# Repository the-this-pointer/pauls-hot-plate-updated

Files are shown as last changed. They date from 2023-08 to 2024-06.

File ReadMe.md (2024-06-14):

#### Paul's Hotplate Upgraded

This is another version of awesome pauls hot plate project that I am working on. I designed a pcb for the project because I don't have access to the board he used in his project.
The project is not completed yet and I should do some modifications on the enclosure, and I need to change the firmware to support the new PCB. Also the enclosure and the PCB is not tested.

External component libraries located [here](https://github.com/the-this-pointer/kicad-my-libraries)

###### TODO:

- Firmware for new PCB
- Enclosure for new PCB

#### Images

The enclosure files and images are for revision `54e05cd389d`, the boards are changed afterwards and I will redesign enclosure.

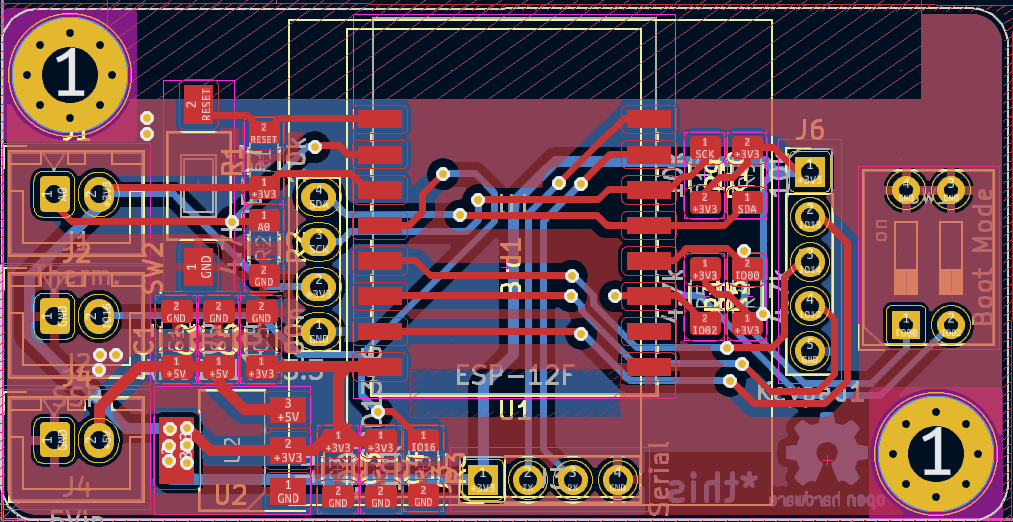
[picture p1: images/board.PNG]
PCB

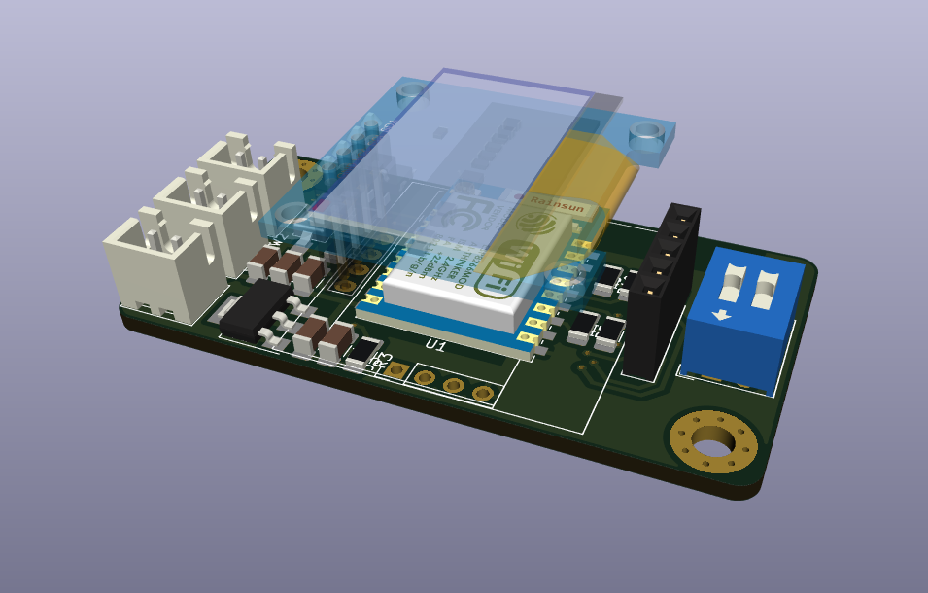
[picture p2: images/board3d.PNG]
3D Model

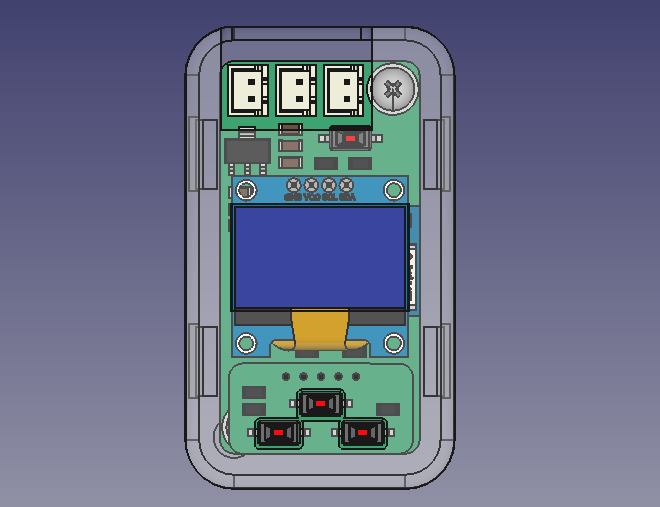
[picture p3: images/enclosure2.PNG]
Enclosure


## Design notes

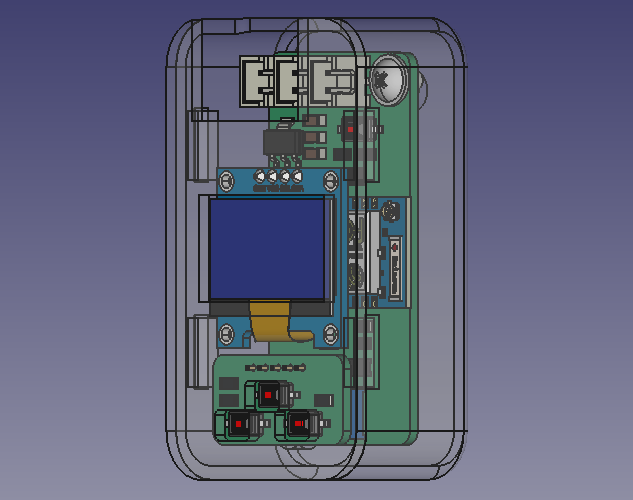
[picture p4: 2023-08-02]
images/enclosure3.PNG

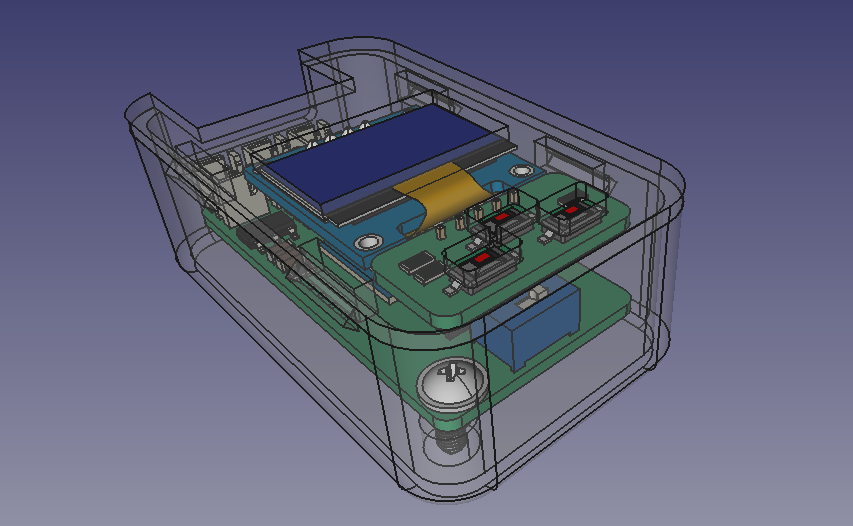
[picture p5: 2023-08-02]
images/enclosure1.PNG

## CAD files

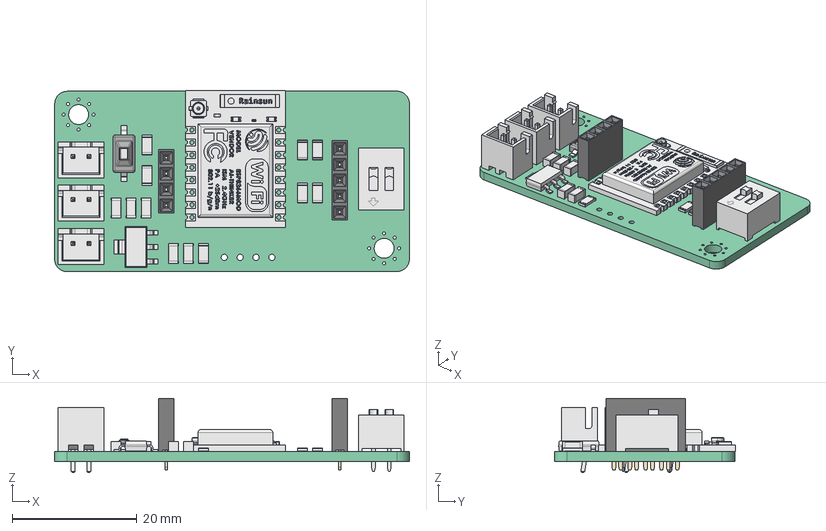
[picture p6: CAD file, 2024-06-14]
enclosure/MainBoard.FCStd
56.9 x 29.0 x 11.9 mm
Pcb_ba79
${REFERENCE}_R_1206_3216Metric_null
${REFERENCE}_JST_B2B_XH_A_null
pines
cuerpo
boton
Pin_One007
Epoxy_Body007
${REFERENCE}_C_1206_3216Metric_null
${REFERENCE}_R_1206_3216Metric_null001
${REFERENCE}_C_1206_3216Metric_null001
Pin_One006
Epoxy_Body006
${REFERENCE}_C_1206_3216Metric_null002
${REFERENCE}_R_1206_3216Metric_null002
ESP07
ESP008
ESP009
ESP010
ESP011
ESP012
ESP013
ESP014
ESP015
ESP016
ESP017
ESP018
ESP019
ESP020
ESP021
ESP022
ESP023
ESP024
ESP025
ESP026
ESP027
ESP028
ESP029
ESP030
ESP031
ESP032
ESP033
ESP034
ESP035
ESP036
ESP037
ESP038
ESP039
ESP040
ESP041
ESP042
ESP043
ESP044
ESP045
ESP046
ESP047
ESP048
ESP049
ESP050
ESP051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

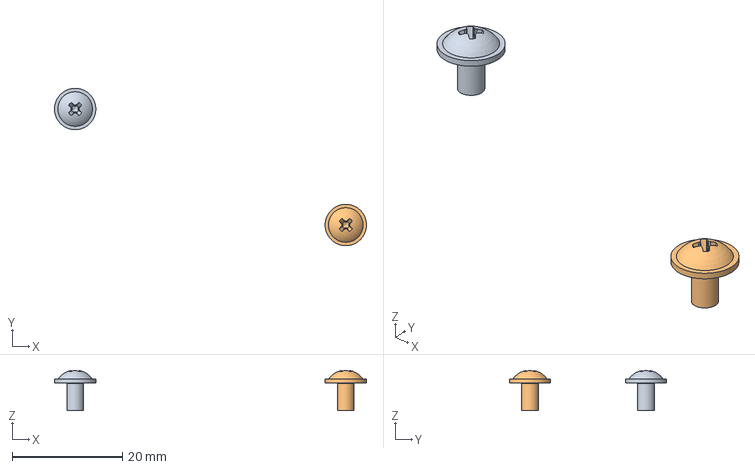
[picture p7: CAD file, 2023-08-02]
enclosure/BoardAssembled.FCStd
56.5 x 28.5 x 7.29 mm
M3x5-Screw
M3x5-Screw001

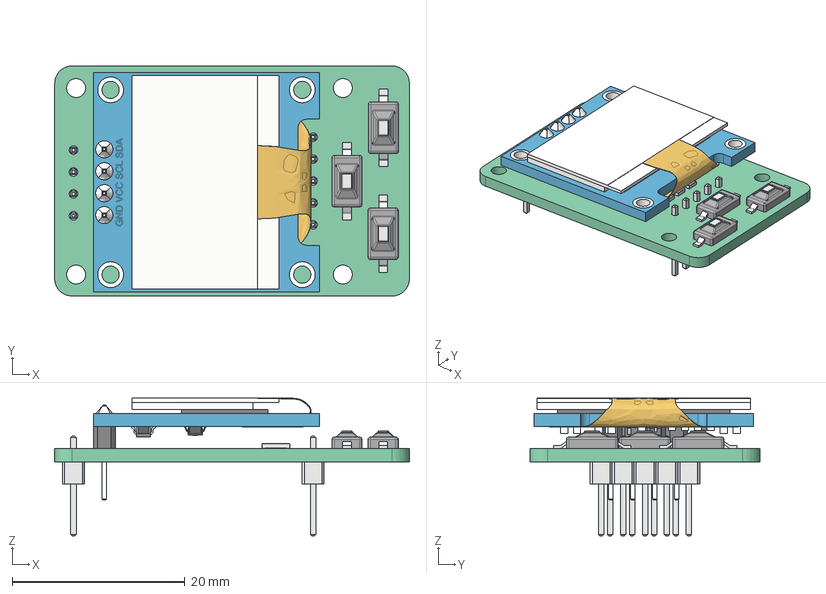
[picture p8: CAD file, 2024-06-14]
enclosure/Keypad.FCStd
41.1 x 26.7 x 15.9 mm
Pcb_ee0a
pines
cuerpo
boton
board
board001
board002
board003
board004
board005
board006
board007
board008
screen
screen001
screen002
pin_header
pin_header001
pin_header002
pin_header003
pin_header004
pin_header005
pin_header006
pin_header007
soldering
soldering001
soldering002
soldering003
smd_capacitor
smd_capacitor001
smd_capacitor002
smd_capacitor (1)
smd_capacitor (1)001
smd_capacitor (1)002
914_smd_resistor
914_smd_resistor001
914_smd_resistor002
472_smd_resistor
472_smd_resistor001
472_smd_resistor002
472_smd_resistor004
472_smd_resistor005
472_smd_resistor006
472_smd_resistor008
472_smd_resistor009
472_smd_resistor010
t4_smd_diode
t4_smd_diode001
t4_smd_diode002
smd_capacitor (2)
smd_capacitor (2)001
smd_capacitor (2)002
smd_capacitor (3)
smd_capacitor (3)001
smd_capacitor (3)002
smd_capacitor (4)
smd_capacitor (4)001
smd_capacitor (4)002
smd_capacitor (5)
smd_capacitor (5)001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

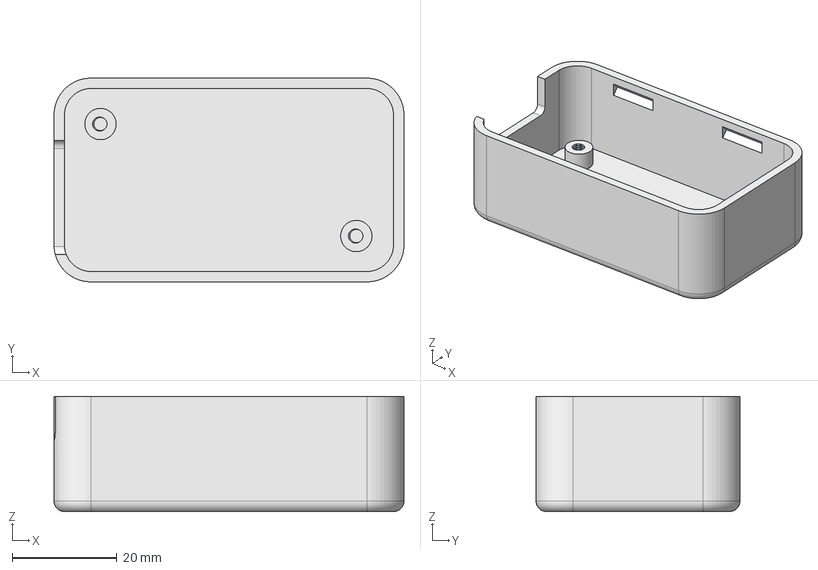
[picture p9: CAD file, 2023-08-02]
enclosure/BoxBody.FCStd
67.0 x 39.0 x 22.0 mm

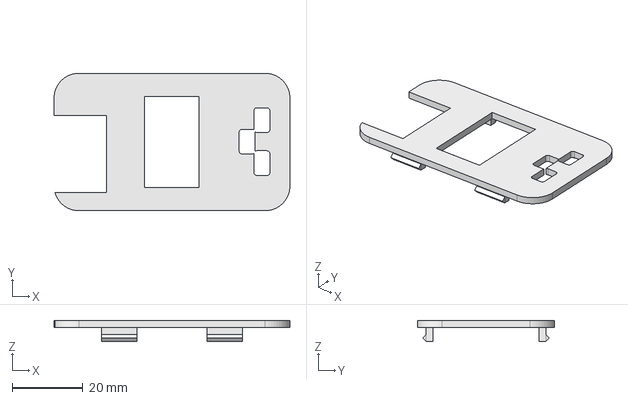
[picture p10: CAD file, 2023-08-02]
enclosure/BoxLead.FCStd
67.0 x 39.0 x 6.00 mm

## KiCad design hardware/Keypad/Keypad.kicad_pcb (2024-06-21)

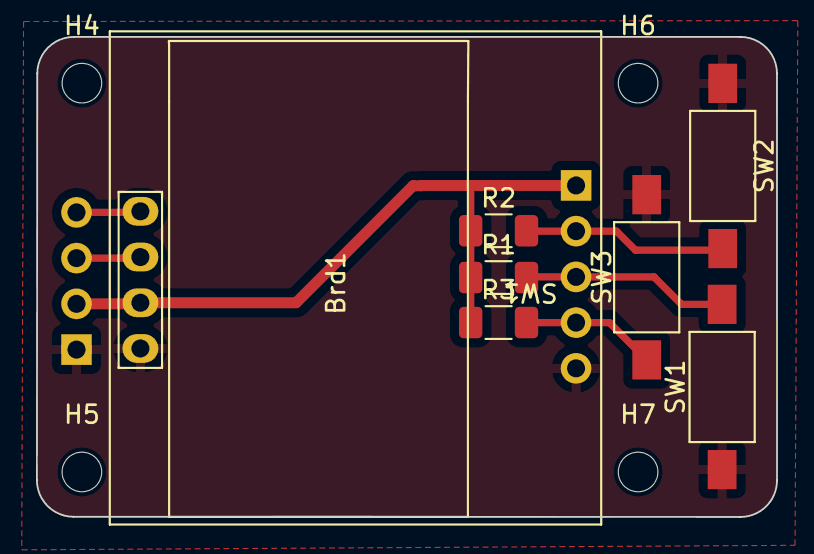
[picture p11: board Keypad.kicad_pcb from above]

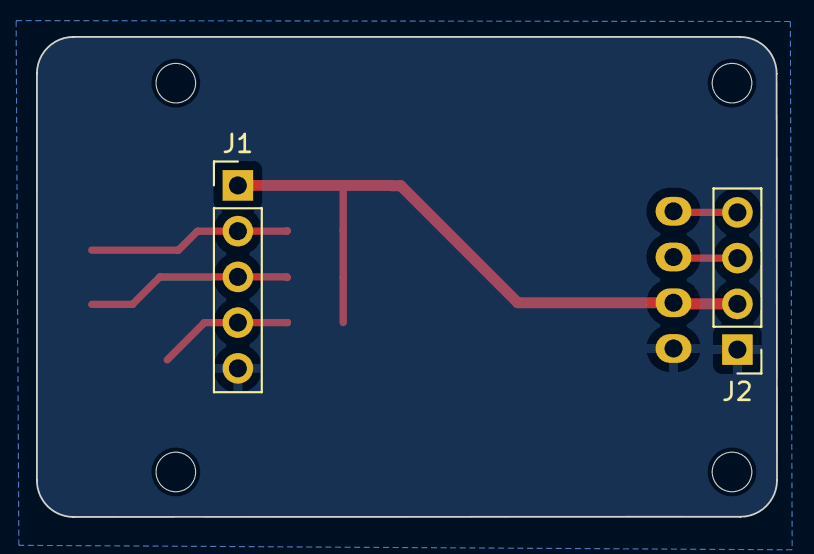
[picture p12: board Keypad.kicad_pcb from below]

Board: 2 copper layers, 41.1 x 26.7 mm, 13 parts (2 on the bottom side), 7 nets.

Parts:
Brd1: SSD1306; 128x64OLED
H4, H5, H6, H7: MountingHole; MountingHole_2.2mm_M2
J1: Keypad1; PinHeader_1x05_P2.54mm_Vertical
J2: LCD; PinHeader_1x04_P2.54mm_Vertical
R1, R2, R3: 10k; R_1206_3216Metric_Pad1.30x1.75mm_HandSolder
SW1: LEFT; SW_SPST_FSMSM
SW2: RIGHT; SW_SPST_FSMSM
SW3: SET; SW_SPST_FSMSM

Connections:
+3V3: Brd1.2 (VCC), J1.1, J2.2, R1.1, R2.1, R3.1
/IO12: J1.4, R3.2, SW3.2 (B)
/IO13: J1.2, R2.2, SW2.2 (B)
/IO14: J1.3, R1.2, SW1.2 (B)
/SCK: Brd1.3 (SCL), J2.3
/SDA: Brd1.4 (SDA), J2.4
GND: Brd1.1 (GND), J1.5, J2.1, SW1.1 (A), SW2.1 (A), SW3.1 (A)

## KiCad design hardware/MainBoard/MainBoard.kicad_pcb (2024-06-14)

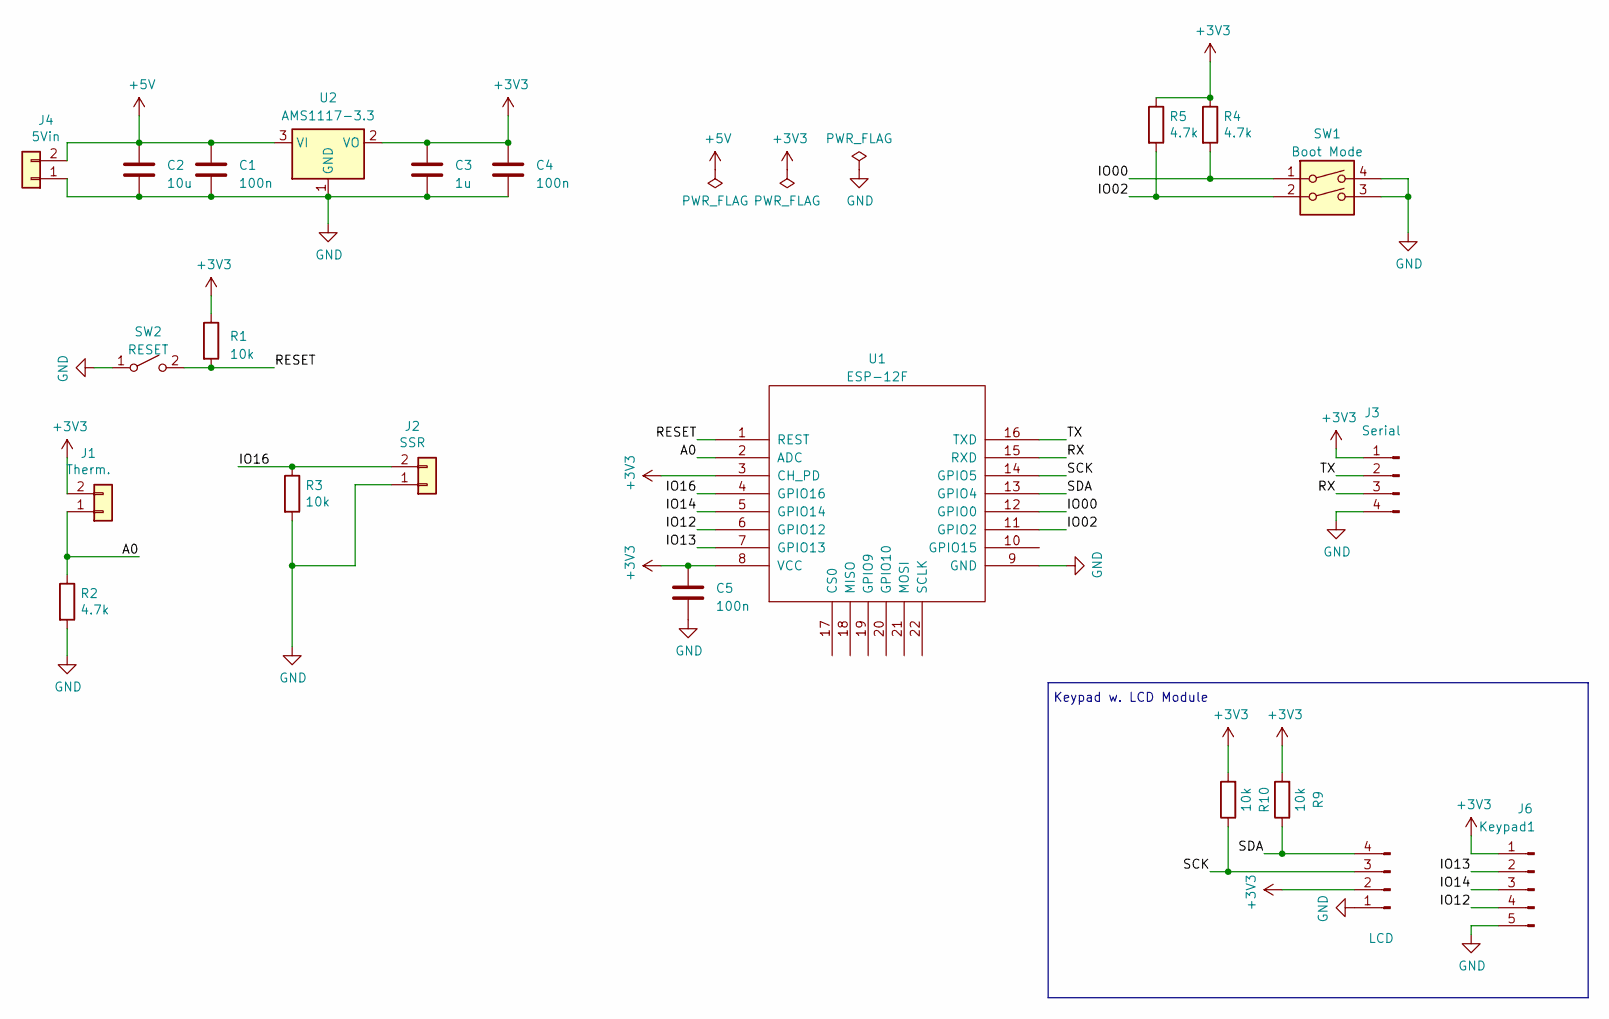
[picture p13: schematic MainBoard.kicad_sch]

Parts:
C1, C4, C5: 100n; C_1206_3216Metric_Pad1.33x1.80mm_HandSolder
C2: 10u; C_1206_3216Metric_Pad1.33x1.80mm_HandSolder
C3: 1u; C_1206_3216Metric_Pad1.33x1.80mm_HandSolder
J1: Therm.; JST_XH_B2B-XH-A_1x02_P2.50mm_Vertical
J2: SSR; JST_XH_B2B-XH-A_1x02_P2.50mm_Vertical
J3: Serial; PinHeader_1x04_P2.54mm_Vertical
J4: 5Vin; JST_XH_B2B-XH-A_1x02_P2.50mm_Vertical
J5: LCD; PinHeader_1x04_P2.54mm_Vertical
J6: Keypad1; PinHeader_1x05_P2.54mm_Vertical
R1, R3, R9, R10: 10k; R_1206_3216Metric_Pad1.30x1.75mm_HandSolder
R2, R4, R5: 4.7k; R_1206_3216Metric_Pad1.30x1.75mm_HandSolder
SW1: Boot Mode; SW_DIP_SPSTx02_Slide_9.78x7.26mm_W7.62mm_P2.54mm
SW2: RESET; SW_SPST_FSMSM
U1: ESP-12F; ESP-07-RF_Modules
U2: AMS1117-3.3; SOT-223-3_TabPin2

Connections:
+3V3: C3.1, C4.1, C5.1, J1.2, J3.1, J5.2, J6.1, R1.1, R4.1, R5.1, R9.2, R10.2, U1.3 (CH_PD), U1.8 (VCC), U2.2 (VO)
+5V: C1.1, C2.1, J4.2, U2.3 (VI)
/A0: J1.1, R2.1, U1.2 (ADC)
/IO00: R4.2, SW1.1, U1.12 (GPIO0)
/IO02: R5.2, SW1.2, U1.11 (GPIO2)
/IO12: J6.4, U1.6 (GPIO12)
/IO13: J6.2, U1.7 (GPIO13)
/IO14: J6.3, U1.5 (GPIO14)
/IO16: J2.2, R3.1, U1.4 (GPIO16)
/RESET: R1.2, SW2.2 (B), U1.1 (REST)
/RX: J3.3, U1.15 (RXD)
/SCK: J5.3, R10.1, U1.14 (GPIO5)
/SDA: J5.4, R9.1, U1.13 (GPIO4)
/TX: J3.2, U1.16 (TXD)
GND: C1.2, C2.2, C3.2, C4.2, C5.2, J2.1, J3.4, J4.1, J5.1, J6.5, R2.2, R3.2, SW1.3, SW1.4, SW2.1 (A), U1.9 (GND), U2.1 (GND)

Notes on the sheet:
Keypad w. LCD Module

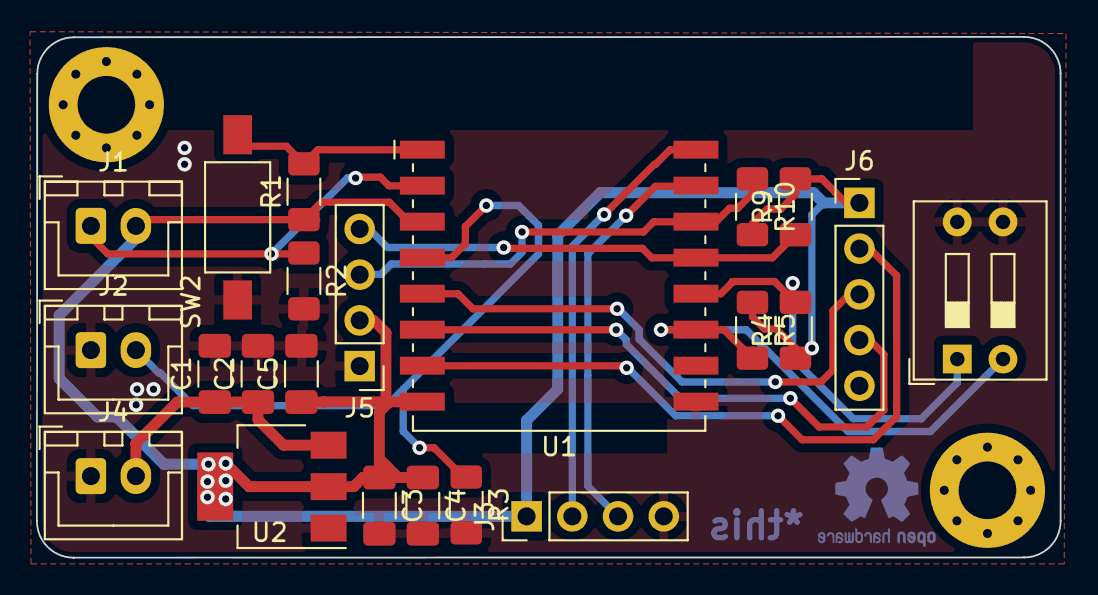
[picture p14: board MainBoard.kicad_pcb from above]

Board: 2 copper layers, 56.9 x 28.9 mm, 22 parts (0 on the bottom side), 15 nets.

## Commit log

2023-07-09 pcb added
    [MainBoard.kicad_pcb, MainBoard.kicad_sch]
2023-07-09 enclosure added
    [BoardAssembled.FCStd, BoxBody.FCStd, BoxLead.FCStd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]
2023-07-13 keypad added
    [Keypad.kicad_pcb, Keypad.kicad_sch]
2023-07-31 gme12864 replaced with ssd1306
    [MainBoard.kicad_pcb, MainBoard.kicad_sch]
2023-07-31 libraries updated
    [MainBoard.kicad_pcb, MainBoard.kicad_sch]
2023-08-02 3d model for keypad connector updated
    [MainBoard.kicad_pcb]
2023-08-02 new design of enclosure based on new lcd and snap fit joints
    [BoardAssembled.FCStd, BoxBody.FCStd, BoxLead.FCStd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]
2023-08-02 fix keypad connector location on board
    [BoardAssembled.FCStd, BoxBody.FCStd, BoxLead.FCStd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]
2023-08-02 fix bolt holes on box body
    [BoardAssembled.FCStd, BoxBody.FCStd, BoxLead.FCStd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]
2024-06-14 redesign pcb files
    [Keypad.FCStd, Keypad.kicad_pcb, Keypad.kicad_sch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]
2024-06-21 minor change on keypad
    [Keypad.kicad_pcb]
